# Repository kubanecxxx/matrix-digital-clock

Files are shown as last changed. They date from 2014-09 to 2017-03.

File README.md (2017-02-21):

#Matrix digital clock

DIY clock with these features:
- LED matrix - 16 x 64 (1024 pixels) or version with 16 x 96 pixels
- DCF Receiver and time synchronization from the radio
- or ESP8826 Wifi module and time synchronization from a NTP server

Project page: https://hackaday.io/project/19949-led-matrix-clock

Version 1 photo
-----
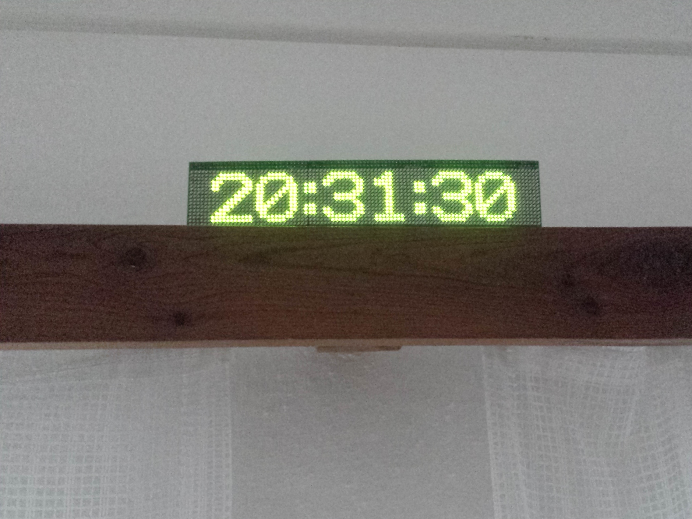
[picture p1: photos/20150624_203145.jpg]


There are actually two versions of this project
- version 1 has 3 LED modules and firmware is much more stupid - no menu; just automatic DCF synchronization every midnight  **whole LED driver must be disabled because it inteferes the DCF radio**. All files used in version 1 are in dedicated branch called version1.
- version 2 has only 2 LED modules and the firmware is much more enhanced - there is a basic button control and menu to setup wifi connection, time source, day lumination, night lumination......; files for version2 are currently in master branch, version2 firmware can be easilly adjusted to use 3 LED modules instead of 2. Hardware is nearly the same but smaller.

Hardware
-----

The hardware consist of these PCBs:
- 2 or 3 pcs LED matrices (each one 16 x 32 LEDs)
- controller board with STM32F100 MCU and shift registers

Firmware
----

Firmware is based on [ChibiOS](http://www.chibios.org) embedded operating system. I use CMake build system so I have fork of the ChibiOS in my repositories. You can use mine version of ChibiOS with this specific commit:

`ccb51e8f5e04b7aec1c0fe87b7e3d1dd5d634bb4` 

You will probably need to adjust path in [CMakeLists.txt](fw/CMakeLists.txt) to the right ChibiOS directory.

Or you can use original ChibiOS version 3 with its Makefile and use the configuration from my [CMakeLists.txt](fw/CMakeLists.txt) to adjust original ChibiOS Makefile.

Build
----

Development toolchain is GNU arm gcc (https://launchpadlibrarian.net/209776202/gcc-arm-none-eabi-4_9-2015q2-20150609-linux.tar.bz2) version 4.9 - it contains interesting newlib library which saves a lot of RAM and hardware floating point support and many other features.

You can flash the MCU via openocd or my [kstlink](https://github.com/kubanecxxx/kstlink) project which is simple gdb server to debug and flash STM microcontrollers (I feel openocd too heavy).

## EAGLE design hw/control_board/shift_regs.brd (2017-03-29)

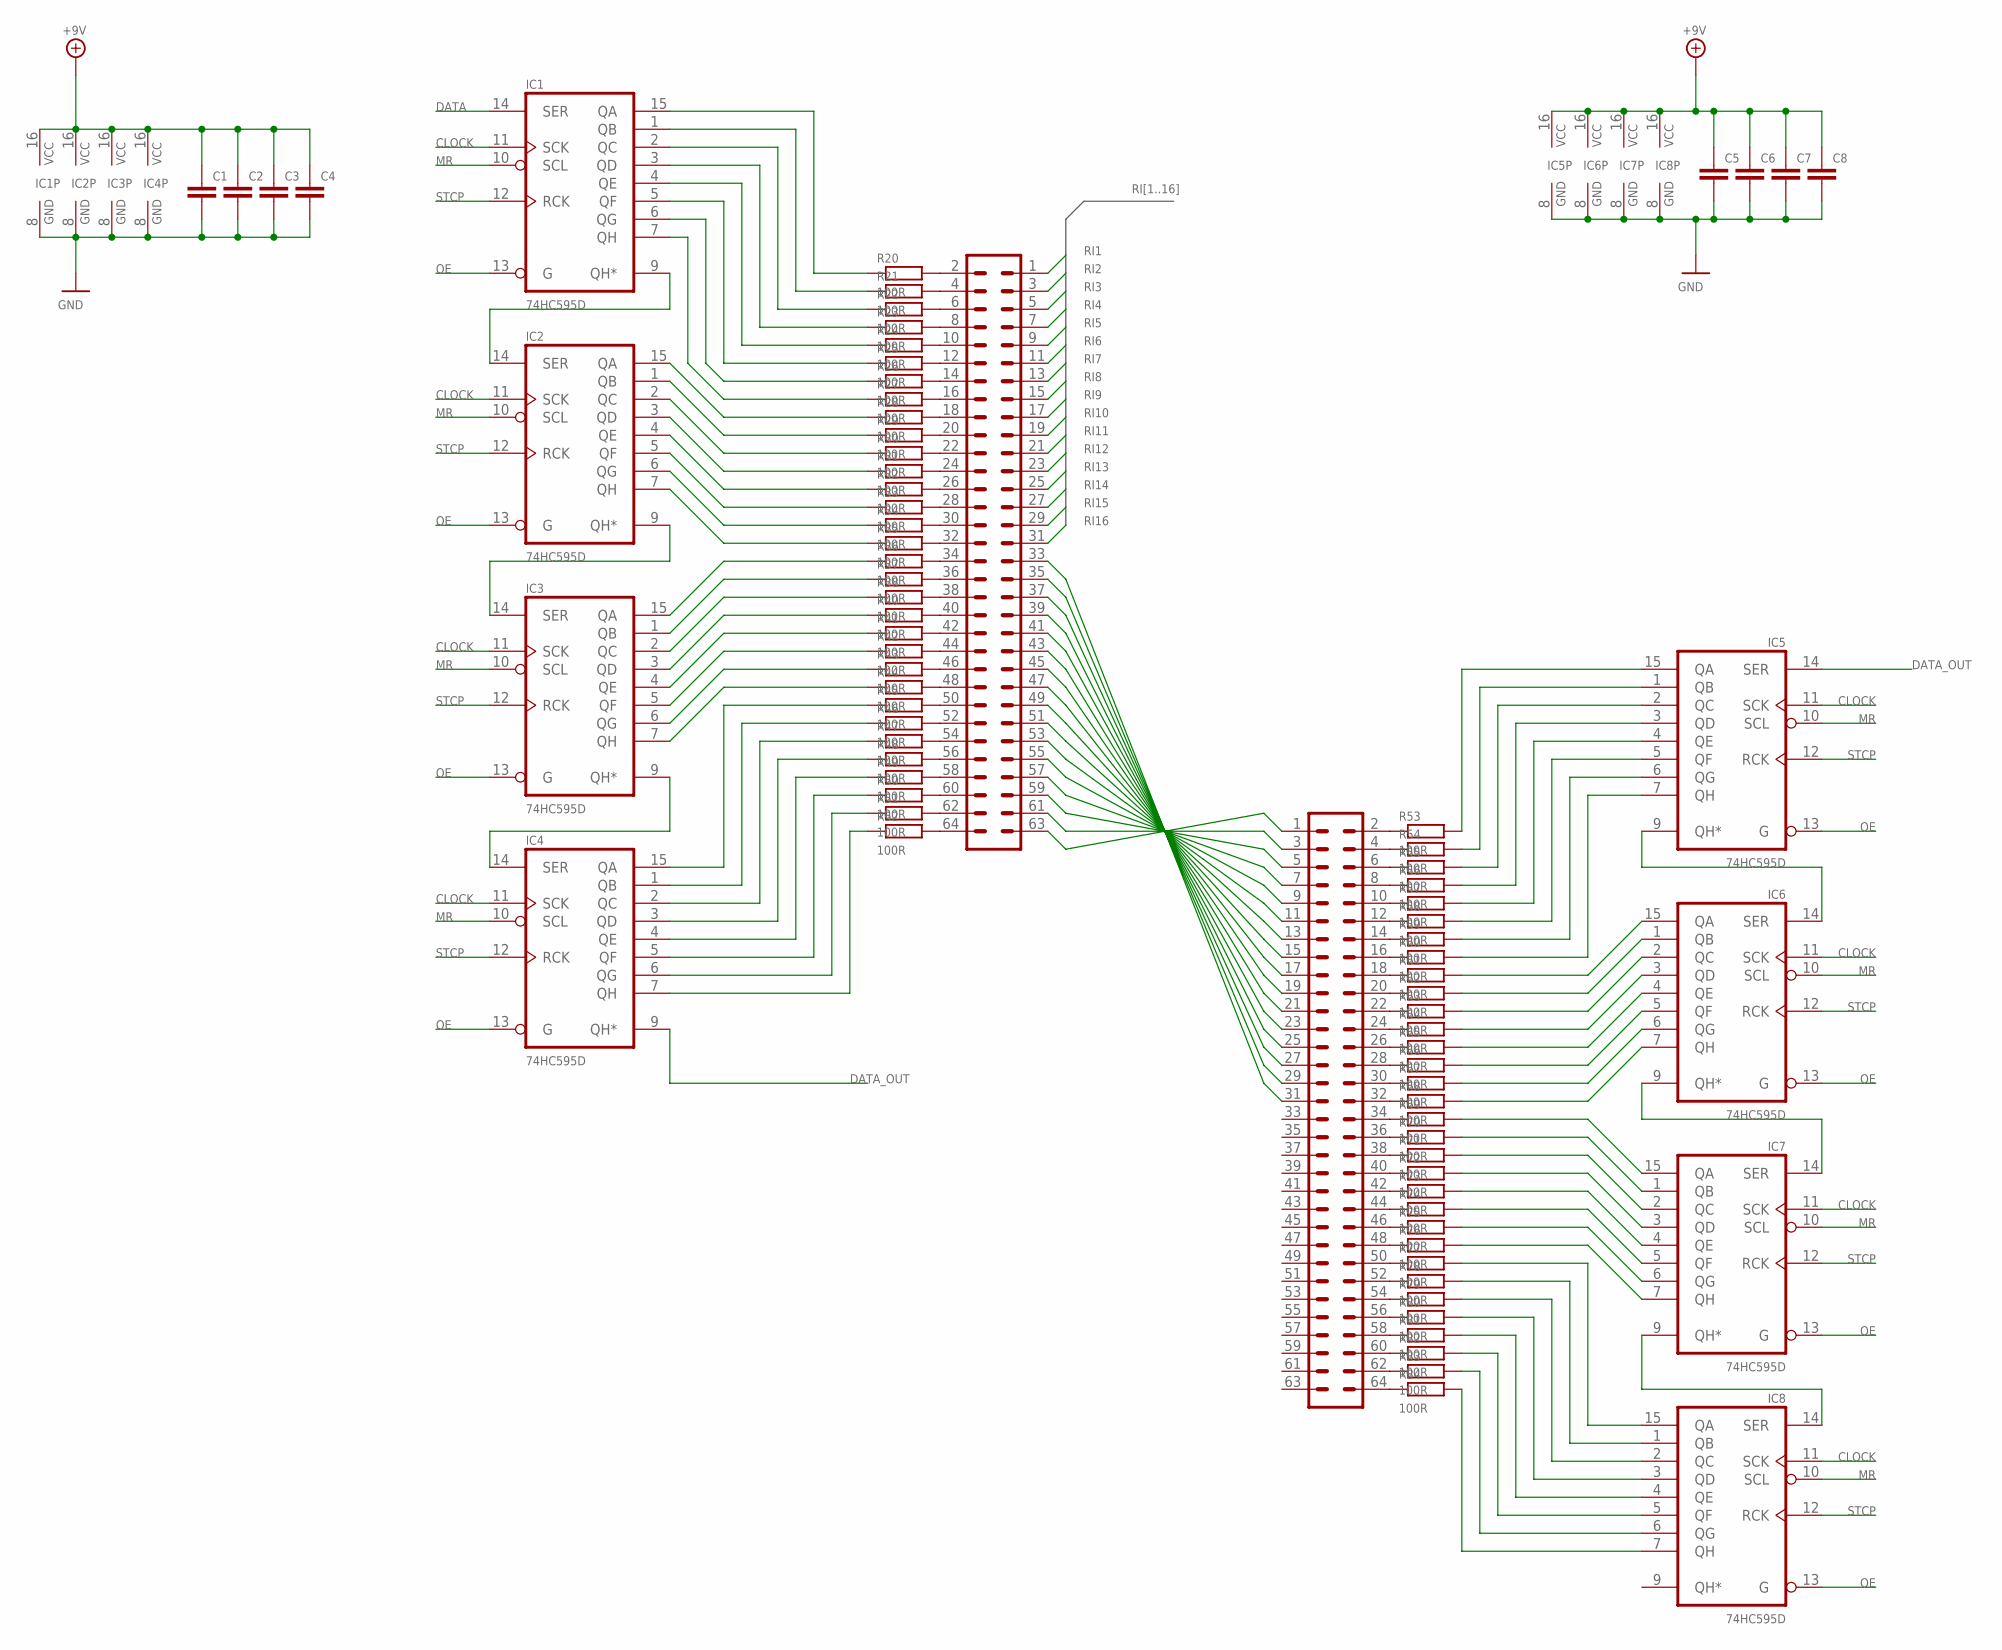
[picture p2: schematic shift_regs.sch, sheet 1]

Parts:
C1, C2, C3, C4, C5, C6, C7, C8: C-EUC0805; C0805
IC1, IC2, IC3, IC4, IC5, IC6, IC7, IC8: 74HC595D; SO16
R20, R21, R22, R23, R24, R25, R26, R27, R28, R29, R30, R31, R32, R33, R34, R35, R36, R37, R38, R40, R41, R42, R43, R44, R45, R46, R47, R48, R49, R50, R51, R52, R53, R54, R55, R56, R57, R58, R59, R60, R61, R62, R63, R64, R65, R66, R67, R68, R69, R70, R71, R72, R73, R74, R75, R76, R77, R78, R79, R80, R81, R82, R83, R84: 100R; R0805
SV1, SV2: ML64

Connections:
+9V: C1.1, C2.1, C3.1, C4.1, C5.1, C6.1, C7.1, C8.1, IC1.16 (VCC), IC2.16 (VCC), IC3.16 (VCC), IC4.16 (VCC), IC5.16 (VCC), IC6.16 (VCC), IC7.16 (VCC), IC8.16 (VCC); also elsewhere on the board
CLOCK: IC1.11 (SCK), IC2.11 (SCK), IC3.11 (SCK), IC4.11 (SCK), IC5.11 (SCK), IC6.11 (SCK), IC7.11 (SCK), IC8.11 (SCK); also elsewhere on the board
DATA: IC1.14 (SER); also elsewhere on the board
DATA_OUT: IC4.9 (QH*), IC5.14 (SER)
GND: C1.2, C2.2, C3.2, C4.2, C5.2, C6.2, C7.2, C8.2, IC1.8 (GND), IC2.8 (GND), IC3.8 (GND), IC4.8 (GND), IC5.8 (GND), IC6.8 (GND), IC7.8 (GND), IC8.8 (GND); also elsewhere on the board
MR: IC1.10 (SCL), IC2.10 (SCL), IC3.10 (SCL), IC4.10 (SCL), IC5.10 (SCL), IC6.10 (SCL), IC7.10 (SCL), IC8.10 (SCL); also elsewhere on the board
unnamed: IC1.9 (QH*), IC2.14 (SER)
unnamed: IC2.9 (QH*), IC3.14 (SER)
unnamed: IC3.9 (QH*), IC4.14 (SER)
unnamed: IC1.1 (QB), R21.1
unnamed: IC1.2 (QC), R22.1
unnamed: IC1.3 (QD), R23.1
unnamed: IC1.4 (QE), R24.1
unnamed: IC1.5 (QF), R25.1
unnamed: IC1.6 (QG), R26.1
unnamed: IC1.7 (QH), R27.1
unnamed: IC1.15 (QA), R20.1
unnamed: IC2.1 (QB), R29.1
unnamed: IC2.2 (QC), R30.1
unnamed: IC2.3 (QD), R31.1
unnamed: IC2.4 (QE), R32.1
unnamed: IC2.5 (QF), R33.1
unnamed: IC2.6 (QG), R34.1
unnamed: IC2.7 (QH), R35.1
unnamed: IC2.15 (QA), R28.1
unnamed: IC3.1 (QB), R37.1
unnamed: IC3.2 (QC), R38.1
unnamed: IC3.3 (QD), R40.1
unnamed: IC3.4 (QE), R41.1
unnamed: IC3.5 (QF), R42.1
unnamed: IC3.6 (QG), R43.1
unnamed: IC3.7 (QH), R44.1
unnamed: IC3.15 (QA), R36.1
unnamed: R20.2, SV1.2
unnamed: R21.2, SV1.4
unnamed: R22.2, SV1.6
unnamed: R23.2, SV1.8
unnamed: R24.2, SV1.10
unnamed: R25.2, SV1.12
unnamed: R26.2, SV1.14
unnamed: R27.2, SV1.16
unnamed: IC5.9 (QH*), IC6.14 (SER)
unnamed: IC6.9 (QH*), IC7.14 (SER)
unnamed: IC7.9 (QH*), IC8.14 (SER)
unnamed: IC5.1 (QB), R54.2
unnamed: IC5.2 (QC), R55.2
unnamed: IC5.3 (QD), R56.2
unnamed: IC5.4 (QE), R57.2
unnamed: IC5.5 (QF), R58.2
unnamed: IC5.6 (QG), R59.2
unnamed: IC5.7 (QH), R60.2
unnamed: IC5.15 (QA), R53.2
unnamed: IC6.1 (QB), R62.2
unnamed: IC6.2 (QC), R63.2
unnamed: IC6.3 (QD), R64.2
unnamed: IC6.4 (QE), R65.2
unnamed: IC6.5 (QF), R66.2
unnamed: IC6.6 (QG), R67.2
unnamed: IC6.7 (QH), R68.2
unnamed: IC6.15 (QA), R61.2
unnamed: IC7.1 (QB), R70.2
unnamed: IC7.2 (QC), R71.2
unnamed: IC7.3 (QD), R72.2
unnamed: IC7.4 (QE), R73.2
unnamed: IC7.5 (QF), R74.2
unnamed: IC7.6 (QG), R75.2
unnamed: IC7.7 (QH), R76.2
unnamed: IC7.15 (QA), R69.2
unnamed: IC8.15 (QA), R77.2
unnamed: IC8.1 (QB), R78.2
unnamed: IC8.2 (QC), R79.2
unnamed: IC8.3 (QD), R80.2
unnamed: IC8.4 (QE), R81.2
unnamed: IC8.5 (QF), R82.2
unnamed: IC8.6 (QG), R83.2
unnamed: IC8.7 (QH), R84.2
unnamed: SV1.63, SV2.1
unnamed: SV1.61, SV2.3
unnamed: SV1.59, SV2.5
unnamed: SV1.57, SV2.7
unnamed: SV1.55, SV2.9
unnamed: SV1.53, SV2.11
unnamed: SV1.51, SV2.13
unnamed: SV1.49, SV2.15
unnamed: SV1.47, SV2.17
unnamed: SV1.45, SV2.19
unnamed: SV1.43, SV2.21
unnamed: SV1.41, SV2.23
unnamed: SV1.39, SV2.25
unnamed: SV1.37, SV2.27
unnamed: SV1.35, SV2.29
unnamed: SV1.33, SV2.31
unnamed: R28.2, SV1.18
unnamed: R29.2, SV1.20
unnamed: R30.2, SV1.22
unnamed: R31.2, SV1.24
unnamed: R32.2, SV1.26
unnamed: R33.2, SV1.28
unnamed: R34.2, SV1.30
unnamed: R35.2, SV1.32
unnamed: R36.2, SV1.34
unnamed: R37.2, SV1.36
unnamed: R38.2, SV1.38
unnamed: R40.2, SV1.40
unnamed: R41.2, SV1.42
unnamed: R42.2, SV1.44
unnamed: R43.2, SV1.46
unnamed: R44.2, SV1.48
unnamed: R45.2, SV1.50
unnamed: R46.2, SV1.52
unnamed: R47.2, SV1.54
unnamed: R48.2, SV1.56
unnamed: R49.2, SV1.58
unnamed: R50.2, SV1.60
unnamed: R51.2, SV1.62
unnamed: R52.2, SV1.64
unnamed: R53.1, SV2.2
unnamed: R54.1, SV2.4
unnamed: R55.1, SV2.6
unnamed: IC4.15 (QA), R45.1
unnamed: IC4.1 (QB), R46.1
unnamed: IC4.2 (QC), R47.1
unnamed: IC4.3 (QD), R48.1
unnamed: IC4.4 (QE), R49.1
unnamed: IC4.5 (QF), R50.1
unnamed: IC4.6 (QG), R51.1
unnamed: IC4.7 (QH), R52.1
unnamed: R56.1, SV2.8
unnamed: R57.1, SV2.10
unnamed: R58.1, SV2.12
unnamed: R59.1, SV2.14
unnamed: R60.1, SV2.16
unnamed: R61.1, SV2.18
unnamed: R62.1, SV2.20
unnamed: R63.1, SV2.22
unnamed: R64.1, SV2.24
unnamed: R65.1, SV2.26
unnamed: R66.1, SV2.28
unnamed: R67.1, SV2.30
unnamed: R68.1, SV2.32
unnamed: R69.1, SV2.34
unnamed: R70.1, SV2.36
unnamed: R71.1, SV2.38
unnamed: R72.1, SV2.40
unnamed: R73.1, SV2.42
unnamed: R74.1, SV2.44
unnamed: R75.1, SV2.46
unnamed: R76.1, SV2.48
unnamed: R77.1, SV2.50
unnamed: R78.1, SV2.52
unnamed: R79.1, SV2.54
unnamed: R80.1, SV2.56
unnamed: R81.1, SV2.58
unnamed: R82.1, SV2.60
unnamed: R83.1, SV2.62
unnamed: R84.1, SV2.64
OE: IC1.13 (G), IC2.13 (G), IC3.13 (G), IC4.13 (G), IC5.13 (G), IC6.13 (G), IC7.13 (G), IC8.13 (G); also elsewhere on the board
RI1: SV1.1; also elsewhere on the board
RI2: SV1.3; also elsewhere on the board
RI3: SV1.5; also elsewhere on the board
RI4: SV1.7; also elsewhere on the board
RI5: SV1.9; also elsewhere on the board
RI6: SV1.11; also elsewhere on the board
RI7: SV1.13; also elsewhere on the board
RI8: SV1.15; also elsewhere on the board
RI9: SV1.17; also elsewhere on the board
RI10: SV1.19; also elsewhere on the board
RI11: SV1.21; also elsewhere on the board
RI12: SV1.23; also elsewhere on the board
RI13: SV1.25; also elsewhere on the board
RI14: SV1.27; also elsewhere on the board
RI15: SV1.29; also elsewhere on the board
RI16: SV1.31; also elsewhere on the board
STCP: IC1.12 (RCK), IC2.12 (RCK), IC3.12 (RCK), IC4.12 (RCK), IC5.12 (RCK), IC6.12 (RCK), IC7.12 (RCK), IC8.12 (RCK); also elsewhere on the board

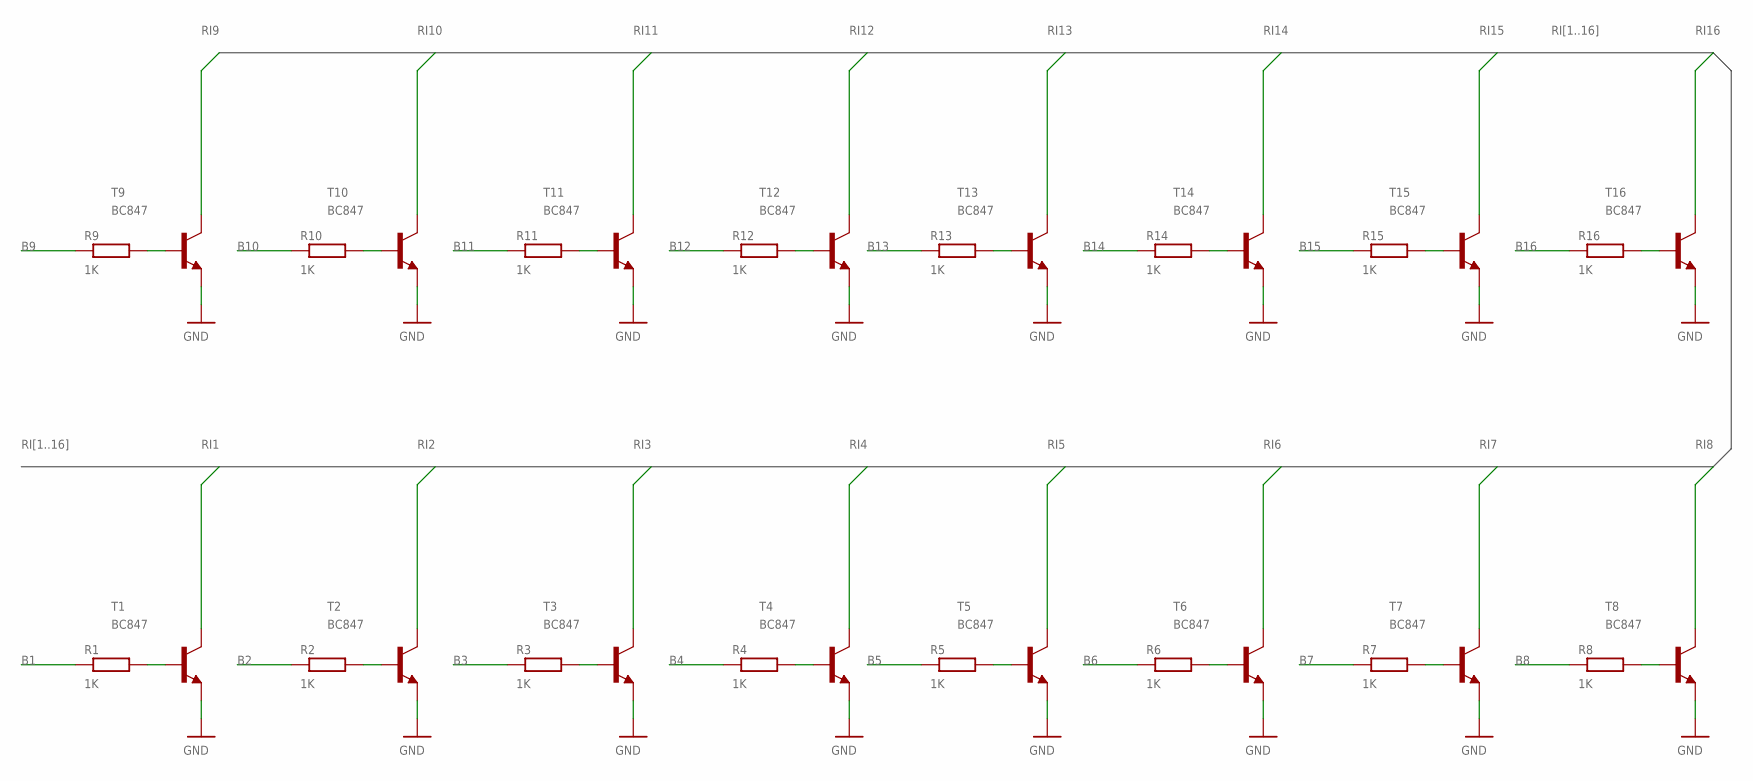
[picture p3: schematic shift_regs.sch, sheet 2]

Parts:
R1, R2, R3, R4, R5, R6, R7, R8, R9, R10, R11, R12, R13, R14, R15, R16: 1K; R0805
T1, T2, T3, T4, T5, T6, T7, T8, T9, T10, T11, T12, T13, T14, T15, T16: BC847; SOT23

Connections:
B1: R1.1; also elsewhere on the board
B2: R2.1; also elsewhere on the board
B3: R3.1; also elsewhere on the board
B4: R4.1; also elsewhere on the board
B5: R5.1; also elsewhere on the board
B6: R6.1; also elsewhere on the board
B7: R7.1; also elsewhere on the board
B8: R8.1; also elsewhere on the board
B9: R9.1; also elsewhere on the board
B10: R10.1; also elsewhere on the board
B11: R11.1; also elsewhere on the board
B12: R12.1; also elsewhere on the board
B13: R13.1; also elsewhere on the board
B14: R14.1; also elsewhere on the board
B15: R15.1; also elsewhere on the board
B16: R16.1; also elsewhere on the board
GND: T1.2 (E), T2.2 (E), T3.2 (E), T4.2 (E), T5.2 (E), T6.2 (E), T7.2 (E), T8.2 (E), T9.2 (E), T10.2 (E), T11.2 (E), T12.2 (E), T13.2 (E), T14.2 (E), T15.2 (E), T16.2 (E); also elsewhere on the board
unnamed: R1.2, T1.1 (B)
unnamed: R2.2, T2.1 (B)
unnamed: R3.2, T3.1 (B)
unnamed: R4.2, T4.1 (B)
unnamed: R5.2, T5.1 (B)
unnamed: R6.2, T6.1 (B)
unnamed: R7.2, T7.1 (B)
unnamed: R8.2, T8.1 (B)
unnamed: R9.2, T9.1 (B)
unnamed: R10.2, T10.1 (B)
unnamed: R11.2, T11.1 (B)
unnamed: R12.2, T12.1 (B)
unnamed: R13.2, T13.1 (B)
unnamed: R14.2, T14.1 (B)
unnamed: R15.2, T15.1 (B)
unnamed: R16.2, T16.1 (B)
RI1: T1.3 (C); also elsewhere on the board
RI2: T2.3 (C); also elsewhere on the board
RI3: T3.3 (C); also elsewhere on the board
RI4: T4.3 (C); also elsewhere on the board
RI5: T5.3 (C); also elsewhere on the board
RI6: T6.3 (C); also elsewhere on the board
RI7: T7.3 (C); also elsewhere on the board
RI8: T8.3 (C); also elsewhere on the board
RI9: T9.3 (C); also elsewhere on the board
RI10: T10.3 (C); also elsewhere on the board
RI11: T11.3 (C); also elsewhere on the board
RI12: T12.3 (C); also elsewhere on the board
RI13: T13.3 (C); also elsewhere on the board
RI14: T14.3 (C); also elsewhere on the board
RI15: T15.3 (C); also elsewhere on the board
RI16: T16.3 (C); also elsewhere on the board

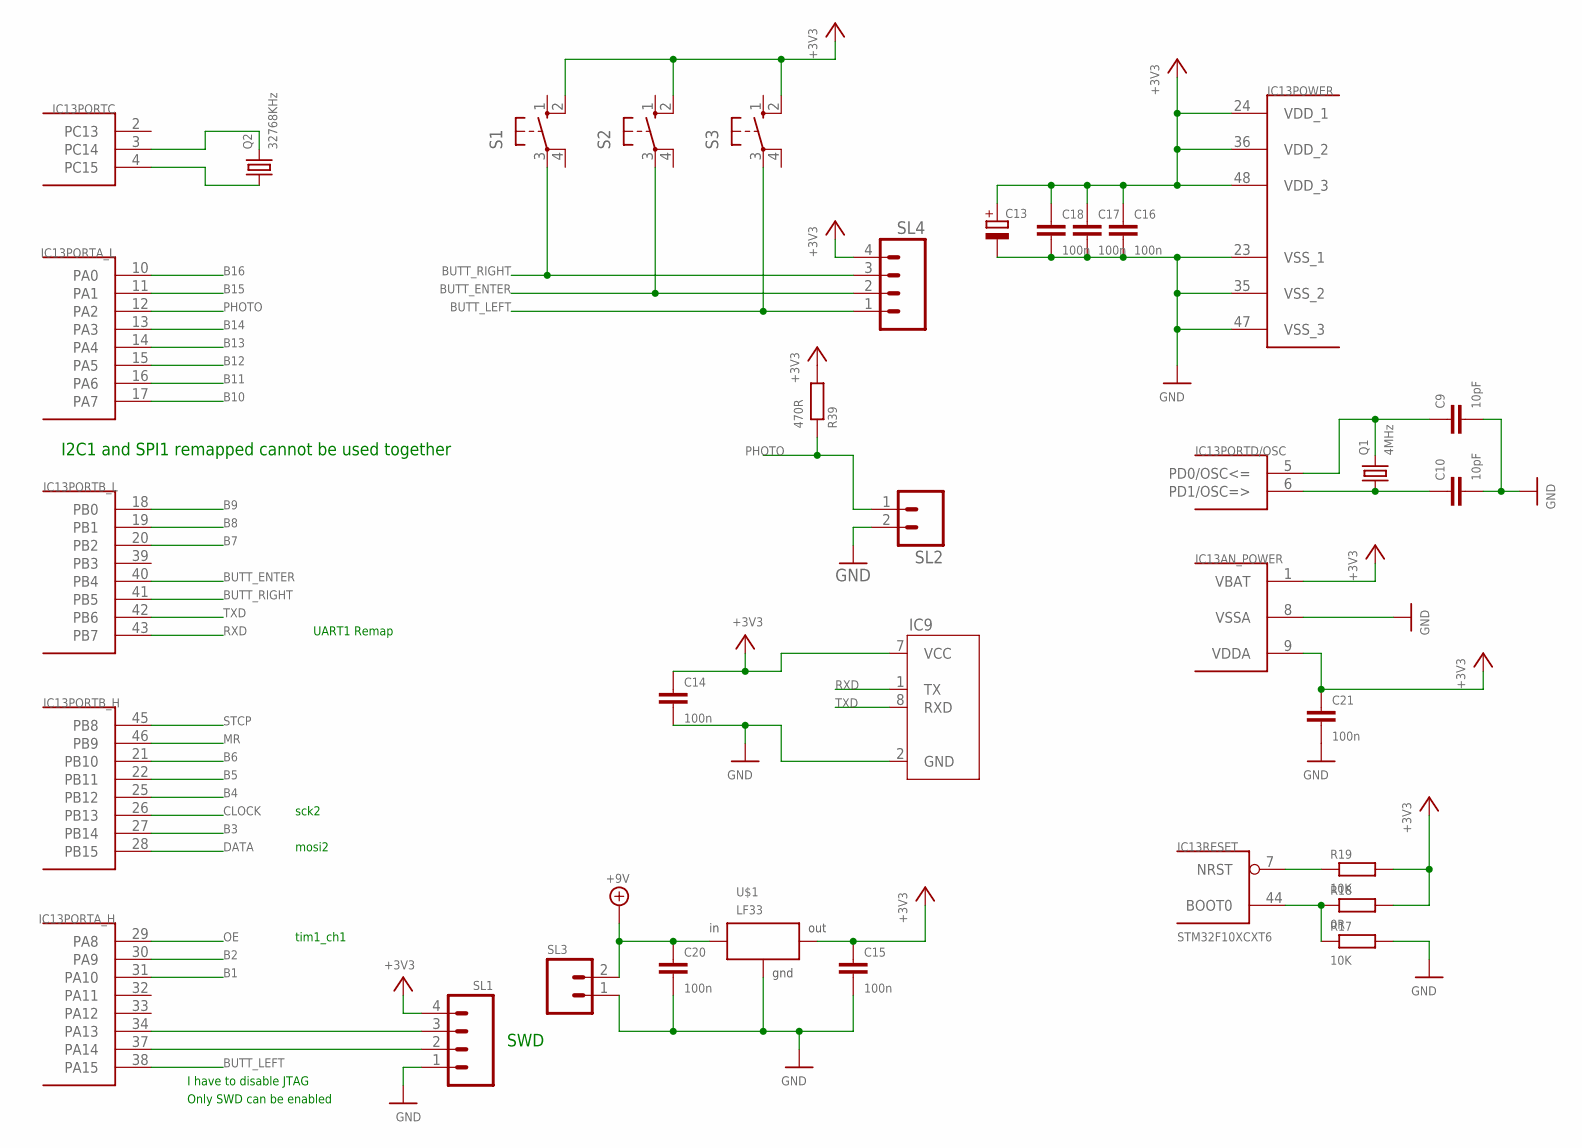
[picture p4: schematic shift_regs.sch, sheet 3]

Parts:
C9, C10: 10pF; C0805
C13: CPOL-EUE2.5-6; E2,5-6
C14, C15, C16, C17, C18, C20, C21: 100n; C0805
IC9: ESP8266; NRF24L01
IC13: STM32F10XCXT6; TQFP48
Q1: 4MHz; HC49/S
Q2: 32768KHz; TC26V
R17, R19: 10K; R0805
R18: 0R; R0805
R39: 470R; R0805
S1, S2, S3: 10-XX; B3F-10XX
SL1, SL4: M04; 04P
SL2, SL3: M02; 02P
U$1: LF33; DPACK

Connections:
+3V3: C13.+, C14.1, C15.1, C16.1, C17.1, C18.1, C21.1, IC9.7 (VCC), IC13.1 (VBAT), IC13.9 (VDDA), IC13.24 (VDD_1), IC13.36 (VDD_2), IC13.48 (VDD_3), R18.2, R19.2, R39.2, S1.2 (S1), S2.2 (S1), S3.2 (S1), SL1.4, SL4.4, U$1.3 (OUT)
+9V: C20.1, SL3.2, U$1.1 (IN); also elsewhere on the board
B1: IC13.31 (PA10); also elsewhere on the board
B2: IC13.30 (PA9); also elsewhere on the board
B3: IC13.27 (PB14); also elsewhere on the board
B4: IC13.25 (PB12); also elsewhere on the board
B5: IC13.22 (PB11); also elsewhere on the board
B6: IC13.21 (PB10); also elsewhere on the board
B7: IC13.20 (PB2); also elsewhere on the board
B8: IC13.19 (PB1); also elsewhere on the board
B9: IC13.18 (PB0); also elsewhere on the board
B10: IC13.17 (PA7); also elsewhere on the board
B11: IC13.16 (PA6); also elsewhere on the board
B12: IC13.15 (PA5); also elsewhere on the board
B13: IC13.14 (PA4); also elsewhere on the board
B14: IC13.13 (PA3); also elsewhere on the board
B15: IC13.11 (PA1); also elsewhere on the board
B16: IC13.10 (PA0); also elsewhere on the board
BUTT_ENTER: IC13.40 (PB4), S2.3, SL4.2
BUTT_LEFT: IC13.38 (PA15), S3.3, SL4.1
BUTT_RIGHT: IC13.41 (PB5), S1.3, SL4.3
CLOCK: IC13.26 (PB13); also elsewhere on the board
DATA: IC13.28 (PB15); also elsewhere on the board
GND: C9.2, C10.2, C13.-, C14.2, C15.2, C16.2, C17.2, C18.2, C20.2, C21.2, IC9.2 (GND), IC13.8 (VSSA), IC13.23 (VSS_1), IC13.35 (VSS_2), IC13.47 (VSS_3), R17.2, SL1.1, SL2.2, SL3.1, U$1.2 (GND); also elsewhere on the board
MR: IC13.46 (PB9); also elsewhere on the board
unnamed: IC13.3 (PC14), Q2.2
unnamed: IC13.4 (PC15), Q2.1
unnamed: C9.1, IC13.5 (PD0/OSC<=), Q1.2
unnamed: C10.1, IC13.6 (PD1/OSC=>), Q1.1
unnamed: IC13.44 (BOOT0), R17.1, R18.1
NRST: IC13.7 (NRST), R19.1
OE: IC13.29 (PA8); also elsewhere on the board
PHOTO: IC13.12 (PA2), R39.1, SL2.1
RXD: IC9.1 (TX), IC13.43 (PB7)
STCP: IC13.45 (PB8); also elsewhere on the board
SWDCLK: IC13.37 (PA14), SL1.2
SWDIO: IC13.34 (PA13), SL1.3
TXD: IC9.8 (RXD), IC13.42 (PB6)

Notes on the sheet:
SWD
I have to disable JTAG
I2C1 and SPI1 remapped cannot be used together
Only SWD can be enabled
sck2
mosi2
tim1_ch1
UART1 Remap

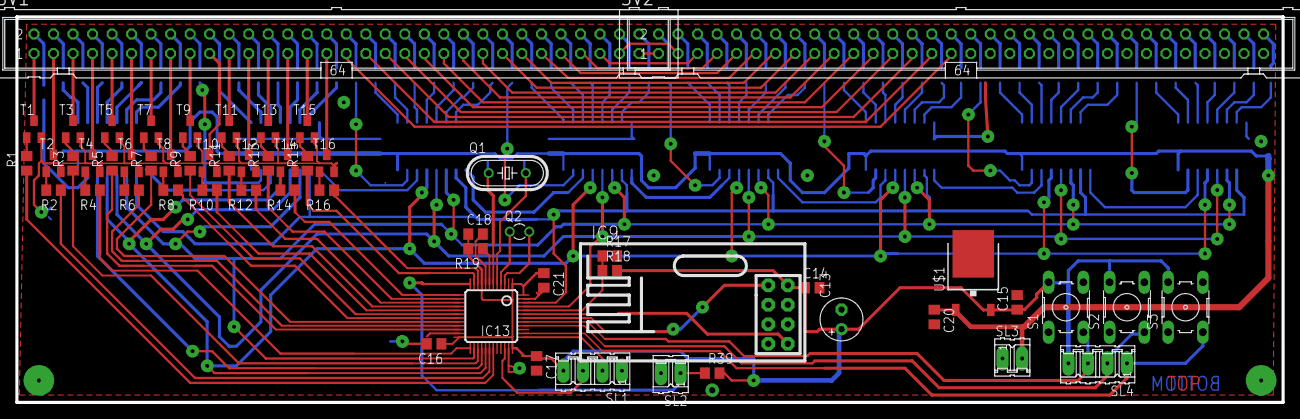
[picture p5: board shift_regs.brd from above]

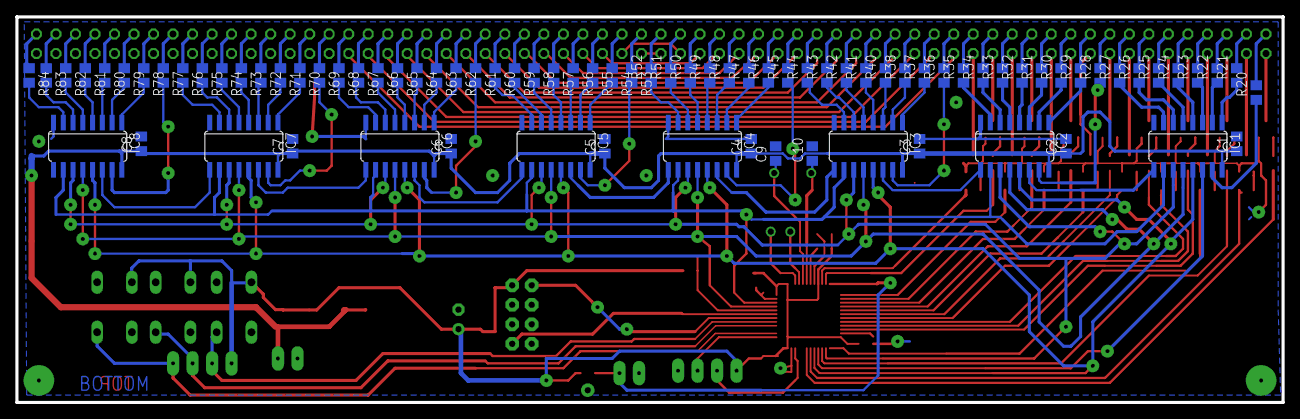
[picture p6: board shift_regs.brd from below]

Board: 2 copper layers, 164.8 x 50.2 mm, 140 parts (82 on the bottom side), 221 nets.

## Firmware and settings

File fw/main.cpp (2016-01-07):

/*
 ChibiOS/RT - Copyright (C) 2006-2013 Giovanni Di Sirio

 Licensed under the Apache License, Version 2.0 (the "License");
 you may not use this file except in compliance with the License.
 You may obtain a copy of the License at

 http://www.apache.org/licenses/LICENSE-2.0

 Unless required by applicable law or agreed to in writing, software
 distributed under the License is distributed on an "AS IS" BASIS,
 WITHOUT WARRANTIES OR CONDITIONS OF ANY KIND, either express or implied.
 See the License for the specific language governing permissions and
 limitations under the License.
 */

#include "ch.h"
#include "hal.h"
#include "scheduler.hpp"
#include "matrix_driver.h"
#include "matrix_abstraction.h"
#include "menu.h"
#include "rtc_control.h"

static void blik(arg_t);
static void cb(arg_t);
static Scheduler s1(blik, NULL, MS2ST(3000));
static Scheduler s2(cb, NULL, MS2ST(10000), ONCE);
static void config_matrix();
static void start_watchdog();

systime_t sysTime;

/*
 * Application entry point.
 */

static Menu menu;

int main(void)
{
    halInit();
    chSysInit();

    config_matrix();
    //ma_init();
    ma_set_brightness(0);
    //ma_select_function(DAY_TIME);

    menu.Init();
    rtc_control_Init();

	while (TRUE)
	{
        Scheduler::Play();
        sysTime = chVTGetSystemTime();
        chThdSleepMilliseconds(1);
	}


	return 1;
}


void cb(void * a)
{
	ma_set_brightness(0);
	//dcf_play();
    s1.Register();

}


#if 1

void blik(void * a)
{             /*
    if (dcf_ready())
    {
        //daytime
        if (dcf_getTime() > 21600 && dcf_getTime() < 79200)
        {
            ma_select_function(DAY_TIME);
            ma_set_brightness(2000);
        }
        else
        {
            ma_select_function(NIGHT_TIME);
            ma_set_brightness(80);
        }
    }

    if ((dcf_getTime() < 60 || !dcf_valid()) && dcf_ready())
        dcf_play();
                       */
}

void config_matrix()
{

	static const matrix_gpio_t gpio[16] =
	{
	{ GPIOA, 10 },
	{ GPIOA, 9 },
	{
	GPIOB, 14 },
	{ GPIOB, 12 },
	{ GPIOB, 11 },
	{ GPIOB, 10 },
	{ GPIOB, 2 },
	{
	GPIOB, 1 },
	{ GPIOB, 0 },
	{ GPIOA, 7 },
	{ GPIOA, 6 },
	{ GPIOA, 5 },
	{ GPIOA, 4 },
	{ GPIOA, 3 },
    { GPIOA, 1 },
    { GPIOA, 0 } };

	static const PWMConfig pwmconfig =
	{ 24000000, 1100, NULL,
	{
	{
	PWM_OUTPUT_ACTIVE_LOW, NULL },
	{ PWM_OUTPUT_DISABLED, NULL },
	{
	PWM_OUTPUT_DISABLED, NULL },
	{ PWM_OUTPUT_DISABLED, NULL } }, 0 };

	static const matrix_config_t matrix_config =
	{ &SPID2, &GPTD2, gpio, &PWMD1, 0 };

	pwmStart(&PWMD1, &pwmconfig);

	DBGMCU->CR |= DBGMCU_CR_DBG_TIM2_STOP;
    DBGMCU->CR |= DBGMCU_CR_DBG_TIM3_STOP;
    matrix_init(&matrix_config);
	matrix_start();
}
#endif


extern "C" void __cxa_pure_virtual(void)
{
    asm("bkpt");
    while(1);
}

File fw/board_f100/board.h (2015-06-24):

/*
    ChibiOS/RT - Copyright (C) 2006,2007,2008,2009,2010,
                 2011,2012 Giovanni Di Sirio.

    This file is part of ChibiOS/RT.

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
    You should have received a copy of the GNU General Public License
    along with this program.  If not, see <http://www.gnu.org/licenses/>.
*/

#ifndef _BOARD_H_
#define _BOARD_H_

/*
 * Setup for STMicroelectronics STM32VL-Discovery board.
 */

/*
 * Board identifier.
 */
//#define BOARD_ST_STM32VL_DISCOVERY
#define BOARD_NAME              "ST Digital clock"

/*
 * Board frequencies.
 */
#define STM32_LSECLK            32768
#define STM32_HSECLK            4000000

/*
 * MCU type, supported types are defined in ./os/hal/platforms/hal_lld.h.
 */
#define STM32F10X_MD_VL

/*
 * IO pins assignments.
 */
#define GPIOA_BUTTON            0
#define GPIOA_SPI1NSS           4

#define GPIOB_SPI2NSS           12

#define GPIOC_LED4              8
#define GPIOC_LED3              9

/*
 * I/O ports initial setup, this configuration is established soon after reset
 * in the initialization code.
 *
 * The digits have the following meaning:
 *   0 - Analog input.
 *   1 - Push Pull output 10MHz.
 *   2 - Push Pull output 2MHz.
 *   3 - Push Pull output 50MHz.
 *   4 - Digital input.
 *   5 - Open Drain output 10MHz.
 *   6 - Open Drain output 2MHz.
 *   7 - Open Drain output 50MHz.
 *   8 - Digital input with PullUp or PullDown resistor depending on ODR.
 *   9 - Alternate Push Pull output 10MHz.
 *   A - Alternate Push Pull output 2MHz.
 *   B - Alternate Push Pull output 50MHz.
 *   C - Reserved.
 *   D - Alternate Open Drain output 10MHz.
 *   E - Alternate Open Drain output 2MHz.
 *   F - Alternate Open Drain output 50MHz.
 * Please refer to the STM32 Reference Manual for details.
 */

/*
 * Port A setup.
 * Everything input with pull-up except:
 * PA0  - Normal input      (BUTTON).
 * PA2  - Alternate output  (USART2 TX).
 * PA3  - Normal input      (USART2 RX).
 * PA4  - Push pull output  (SPI1 NSS), initially high state.
 * PA5  - Alternate output  (SPI1 SCK).
 * PA6  - Normal input      (SPI1 MISO).
 * PA7  - Alternate output  (SPI1 MOSI).
 * PA9  - Alternate output  (USART1 TX).
 * PA10 - Normal input      (USART1 RX).
 */
#define VAL_GPIOACRL            0xB4B33333      /*  PA7...PA0 */
#define VAL_GPIOACRH            0x888884B8      /* PA15...PA8 */
#define VAL_GPIOAODR            0xFFFFFFFF

/*
 * Port B setup.
 * Everything input with pull-up except:
 * PB12 - Push pull output  (SPI2 NSS), initially high state.
 * PB13 - Alternate output  (SPI2 SCK).
 * PB14 - Normal input      (SPI2 MISO).
 * PB15 - Alternate output  (SPI2 MOSI).
 */
#define VAL_GPIOBCRL            0x88888888      /*  PB7...PB0 */
#define VAL_GPIOBCRH            0xB4B38888      /* PB15...PB8 */
#define VAL_GPIOBODR            0xFFFFFFFF

/*
 * Port C setup.
 * Everything input with pull-up except:
 * PC8  - Push-pull output (LED4), initially low state.
 * PC9  - Push-pull output (LED3), initially low state.
 */
#define VAL_GPIOCCRL            0x88888888      /*  PC7...PC0 */
#define VAL_GPIOCCRH            0x88888833      /* PC15...PC8 */
#define VAL_GPIOCODR            0xFFFFFCFF

/*
 * Port D setup.
 * Everything input with pull-up except:
 * PD0  - Normal input (XTAL).
 * PD1  - Normal input (XTAL).
 */
#define VAL_GPIODCRL            0x88888844      /*  PD7...PD0 */
#define VAL_GPIODCRH            0x88888888      /* PD15...PD8 */
#define VAL_GPIODODR            0xFFFFFFFF

/*
 * Port E setup.
 * Everything input with pull-up except:
 */
#define VAL_GPIOECRL            0x88888888      /*  PE7...PE0 */
#define VAL_GPIOECRH            0x88888888      /* PE15...PE8 */
#define VAL_GPIOEODR            0xFFFFFFFF

#if !defined(_FROM_ASM_)
#ifdef __cplusplus
extern "C" {
#endif
  void boardInit(void);
#ifdef __cplusplus
}
#endif
#endif /* _FROM_ASM_ */

#endif /* _BOARD_H_ */

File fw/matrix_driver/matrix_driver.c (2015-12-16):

/**
 * @file matrix_driver.c
 * @author kubanec
 * @date 8. 10. 2014
 *
 */

/* Includes ------------------------------------------------------------------*/
#include "hal.h"
#include "ch.h"
#include "matrix_driver.h"

static void gpt_cb(GPTDriver * gpt);

static const matrix_config_t * c;

static void interrupt(void);
static void spi_cb(void);
static void gpt2(void);

static const GPTConfig gpt =
{ 500000, interrupt, 0 };

static const GPTConfig gpt2_cfg =
{
    500000, gpt2, 0
};

static const SPIConfig spi =
{

spi_cb, NULL, 0, 0 // | SPI_CR1_DFF
		};

static uint8_t first_run = 1;
static volatile uint8_t about_to_end = 0;

static uint16_t display_data[MATRIX_ARRAY_COLS][MATRIX_ROWS][MATRIX_BRIGHT];

/* Private function prototypes -----------------------------------------------*/
/* Private functions ---------------------------------------------------------*/

void matrix_demo(void)
{
	static uint8_t a = 48;
	a++;
	int i, j;
	uint16_t pattern;
	uint16_t p1, p2;

	for (i = 0; i < MATRIX_ROWS; i += 1)
	{
		if (a % 2 == 0)
		{
			p1 = 0xaaaa;
			p2 = 0x5555;
		}
		else
		{
			p1 = 0x5555;
			p2 = 0xaaaa;
		}

		if (i % 2 == 0)
			pattern = p1;
		else
			pattern = p2;

		for (j = 0; j < MATRIX_ARRAY_COLS; j++)
			display_data[j][i][0] = pattern;
	}
}

void matrix_init(const matrix_config_t * cfg)
{
	c = cfg;
}

void matrix_pwm_set_period(uint16_t percent)
{
	pwmEnableChannel(c->pwm, c->pwmChannel,
			PWM_PERCENTAGE_TO_WIDTH(c->pwm, percent));
	return;
	palSetPadMode(GPIOA, 8, PAL_MODE_OUTPUT_PUSHPULL);
	palClearPad(GPIOA, 8);
}

static void matrix_hw_test(void)
{
    uint8_t i;


    uint16_t buffer[MATRIX_ARRAY_COLS];

    matrix_pwm_set_period(1000);

    palClearPad(STCP_PORT, STCP_PIN);
    chThdSleepMilliseconds(1);

    for(i = 0 ; i < MATRIX_ARRAY_COLS ; i++)
    {
        buffer[i] = 0xffff;
    }

    if (c->spi->state == SPI_READY)
        spiSend(c->spi, MATRIX_ARRAY_COLS * 2, buffer);

    chThdSleepMilliseconds(1);
    palSetPad(STCP_PORT, STCP_PIN);
    chThdSleepMilliseconds(1);
    palClearPad(STCP_PORT, STCP_PIN);


    for (i = 0; i < 16; i++)
    {
        palSetPad(c->gpio[i].port, c->gpio[i].pin);
        chThdSleepMilliseconds(100);
    }
    while(1);
}

void matrix_start()
{
	//config gpio
	if (!first_run)
	{
		gptStartContinuous(c->timer, 80);
		return;
	}

	int i;
	for (i = 0; i < 16; i++)
	{
		palSetPadMode(c->gpio[i].port, c->gpio[i].pin,
				PAL_MODE_OUTPUT_PUSHPULL);
		palClearPad(c->gpio[i].port, c->gpio[i].pin);
	}

	palSetPadMode(STCP_PORT, STCP_PIN, PAL_MODE_OUTPUT_PUSHPULL);
	palSetPadMode(MR_PORT, MR_PIN, PAL_MODE_OUTPUT_PUSHPULL);
	palSetPadMode(OE_PORT, OE_PIN, PAL_MODE_STM32_ALTERNATE_PUSHPULL);
	//palSetPadMode(OE_PORT,OE_PIN,PAL_MODE_OUTPUT_PUSHPULL);

	//palClearPad(OE_PORT, OE_PIN);
	palClearPad(MR_PORT, MR_PIN);
	chThdSleepMilliseconds(1);

	palSetPad(MR_PORT, MR_PIN);



	//config spi
	palSetPadMode(MATRIX_CLOCK_PORT, MATRIX_CLOCK_PIN,
			PAL_MODE_STM32_ALTERNATE_PUSHPULL);
	palSetPadMode(MATRIX_DATA_PORT, MATRIX_DATA_PIN,
			PAL_MODE_STM32_ALTERNATE_PUSHPULL);
	spiStart(c->spi, &spi);

    //matrix_hw_test();

    //config timer
    gptStart(c->timer, &gpt);
    gptStartContinuous(c->timer, 80);

    gptStart(&GPTD3,&gpt2_cfg);

    matrix_pwm_set_period(1000);
	first_run = 0;
}

void matrix_stop()
{
	int i, j, k;
	for (i = 0; i < MATRIX_ARRAY_COLS; i++)
	{
		for (j = 0; j < MATRIX_ROWS; j++)
		{
			for (k = 0; k < MATRIX_BRIGHT; k++)
				display_data[i][j][k] = (i < 5);
		}
	}

	about_to_end = 1;
	chThdSleepMilliseconds(1);
	while (about_to_end)
	{
		chThdSleepMilliseconds(1);
	}

	for (i = 0; i < 16; i++)
	{
		palClearPad(c->gpio[i].port, c->gpio[i ].pin);

	}
}

void matrix_dcf_led(uint8_t state)
{
	palWritePad(c->gpio[0].port, c->gpio[0].pin, state);
}

void matrix_progress(uint8_t percent)
{
	uint8_t i;
	int16_t p = percent;
	for (i = 0; i < 10; i++)
	{
		palWritePad(c->gpio[i + 3].port, c->gpio[i + 3].pin, p > 0);
		p -= 6;
	}
}

void matrix_clear_screen()
{
	int i, j, k;
	for (i = 0; i < MATRIX_ARRAY_COLS; i++)
	{
		for (j = 0; j < MATRIX_ROWS; j++)
		{
			for (k = 0; k < MATRIX_BRIGHT; k++)
				display_data[i][j][k] = 0;
		}
	}
}
#if 0
void matrix_put_pixel(uint8_t on, uint16_t x, uint16_t y, uint8_t bright)
{
	chDbgAssert(x < MATRIX_COLS, "out of scope", 0);
	chDbgAssert(y < MATRIX_ROWS, "out of scope", 0);
	chDbgAssert(bright< MATRIX_BRIGHT, "out of scope", 0);
	uint8_t slowo = x / 16;
	uint8_t biit = 15 - (x % 16);
	if (on)
	display_data[slowo][y][bright] |= 1 << biit;
	else
	display_data[slowo][y][bright] &= (~1 << biit);
}
#endif

// 16 columns in one word,
void matrix_put_bitmap(const uint16_t * data)
{
	//memcpy(&display_data[0][0][brig],data,MATRIX_ARRAY_COLS*MATRIX_ROWS);

	int i, j, k;
	for (i = 0; i < MATRIX_ARRAY_COLS; i++)
	{
		for (j = 0; j < MATRIX_ROWS; j++)
		{
			for (k = 0; k < MATRIX_BRIGHT; k++)
				display_data[i][j][k] = *data++;
		}
	}
}

static uint16_t current_row;
static uint16_t old_row = 0;

void interrupt(void)
{
	int i;

	static uint8_t brigh_count = 0;
	static uint8_t finish = 0;

	uint16_t d;
	uint16_t r;
	r = matrix_table[brigh_count];
	old_row = current_row;
	current_row++;

	if (current_row > 15)
	{
		current_row = 0;
		brigh_count++;
		if (brigh_count >= 8)
		{
			brigh_count = 0;

		}
	}

	if (current_row == 0 && brigh_count == 0 && about_to_end == 1)
	{
		if (finish == 1)
		{
			finish = 0;
			about_to_end = 0;
			gptStopTimerI(c->timer);
            return;
		}
		else
		{
			finish = 1;
		}
	}

	palClearPad(STCP_PORT, STCP_PIN);

	static uint16_t buffer[MATRIX_ARRAY_COLS];
	for (i = 0; i < MATRIX_ARRAY_COLS; i++)
	{
		//6* 2bytes
		d = display_data[i][current_row][r];
		buffer[i] = (d >> 8) | (d << 8);

	}

	if (c->spi->state == SPI_READY)
		spiStartSendI(c->spi, MATRIX_ARRAY_COLS * 2, buffer);

}

void gpt2(void)
{

}

void spi_cb(void)
{
    int i ;
    for (i = 0; i < 10; i++)
    palClearPad(c->gpio[old_row].port, c->gpio[old_row].pin);
    //gptStartOneShot(&GPTD3,2);
    palSetPad(STCP_PORT, STCP_PIN);
    palSetPad(c->gpio[current_row].port, c->gpio[current_row].pin);
}

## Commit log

2014-09-02 added first hardware - digital matrix PCB start
    [matrix.brd, matrix.sch]
2014-09-09 finished LED matrix PCB and sent to the chinese production
    [matrix.brd, matrix.sch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]
2014-09-25 shift register hardware layout finished
    [matrix2.GBL, matrix2.GBO, matrix2.GBP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]
2014-10-09 finished hardware prototype on my table
    finished led matrix driving with different pixel brightness possibility
    finished part of matrix abstraction layer - text printing and some
    animations - fade, slide
    todo: wireless rf24; modes abstraction and switching, pwm OE
    [shift_regs.brd, shift_regs.sch]
2014-10-16 fixed animations for different font sizes added suppport for different fonts added new led 'font'
    added wireless module rf24 communication with openwrt router
    rtc updating via wirelesss
    [shift_regs.brd, shift_regs.sch]
2015-06-30 hardware corrections
    [shift_regs.brd, shift_regs.sch]
2015-12-15 added advanced version with menu and it uses cmake build system
    [configuration.h]
2015-12-15 added smaller version of hardware - two segments only cmake fixes
    [shift_regs.brd, shift_regs.sch]
2015-12-16 menu working
    [configuration.h]
2017-02-20 great renaming and tidying up
    [configuration.h, shift_regs.brd, shift_regs.sch]
2017-02-20 upgraded hw for version 2 - added header for buttons
    [shift_regs.brd, shift_regs.sch]
2017-02-21 old version removed and put into separate branch called version1
    [configuration.h, shift_regs.brd, shift_regs.sch]
2017-03-29 added control buttons to the control PCB
    [shift_regs.brd, shift_regs.sch]
